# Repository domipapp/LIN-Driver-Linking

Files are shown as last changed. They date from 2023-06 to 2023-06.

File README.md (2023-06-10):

# LIN meghajtó illesztése STK3700 mikrokontrollerhez és visszapillantó tükör vezérlése számítógépről
A project az 5. féléves Témalaboratóium kurzus keretein belül valósult meg. A konzulensem Scherer Balázs volt.
A projekt során meg kellett tervezni egy nyákot olyan kapcsolással amely illeszthető STM3700 mikrokontrollerhez, számítőgéptől kapott LIN üzenetek
megfelelő feszültségszintre konvertálását el tudja végezni és képes elegendő áramot szolgáltani a visszapillantó tükör vezérléséhez.
Az üzenetek dekódolását és a tükör irányítását a mikrokontroller végzi.

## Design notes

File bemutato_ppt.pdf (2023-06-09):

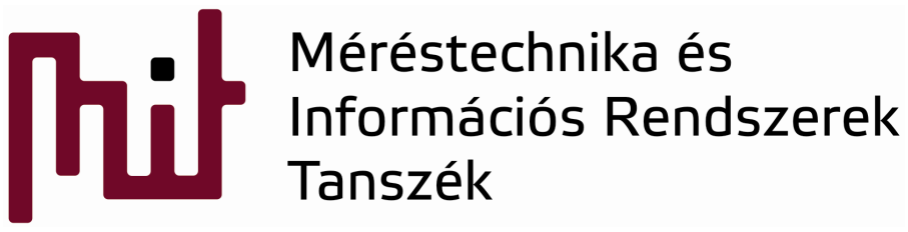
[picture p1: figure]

© BME-MIT 2022 Budapesti Műszaki és Gazdaságtudományi Egyetem Méréstechnika és Információs Rendszerek Tanszék

# BSc Témalaboratórium beszámoló

# Visszapillantó tükör vezérlése LIN hálózaton keresztül

# Papp Dominik Scherer Balázs

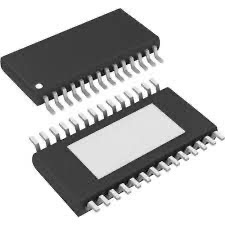
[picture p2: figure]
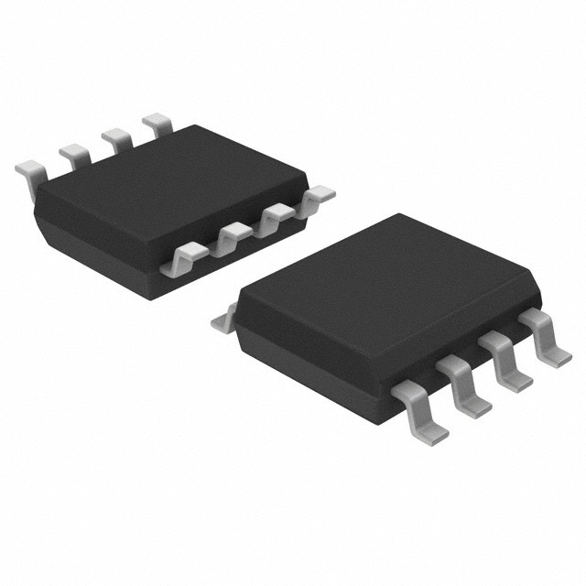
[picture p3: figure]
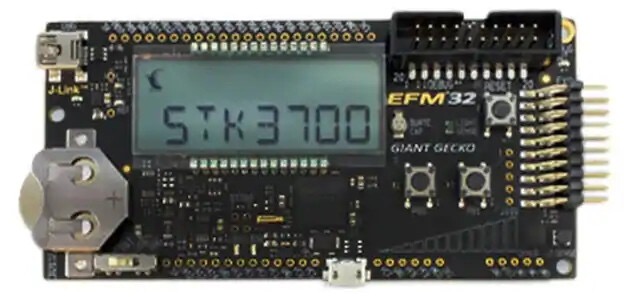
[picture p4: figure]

© BME-MIT 2022 | 2. fólia

# Feldatkírás

# - Motor vezérlés - LIN kommunikáció - Adatfeldolgozás mikrokontrollerrel

# - DRV8844PWPR - TJA1029T/20/1J - STK3700 fejlesztői kártya

# IC-k

# - LIN Adó-Vevő

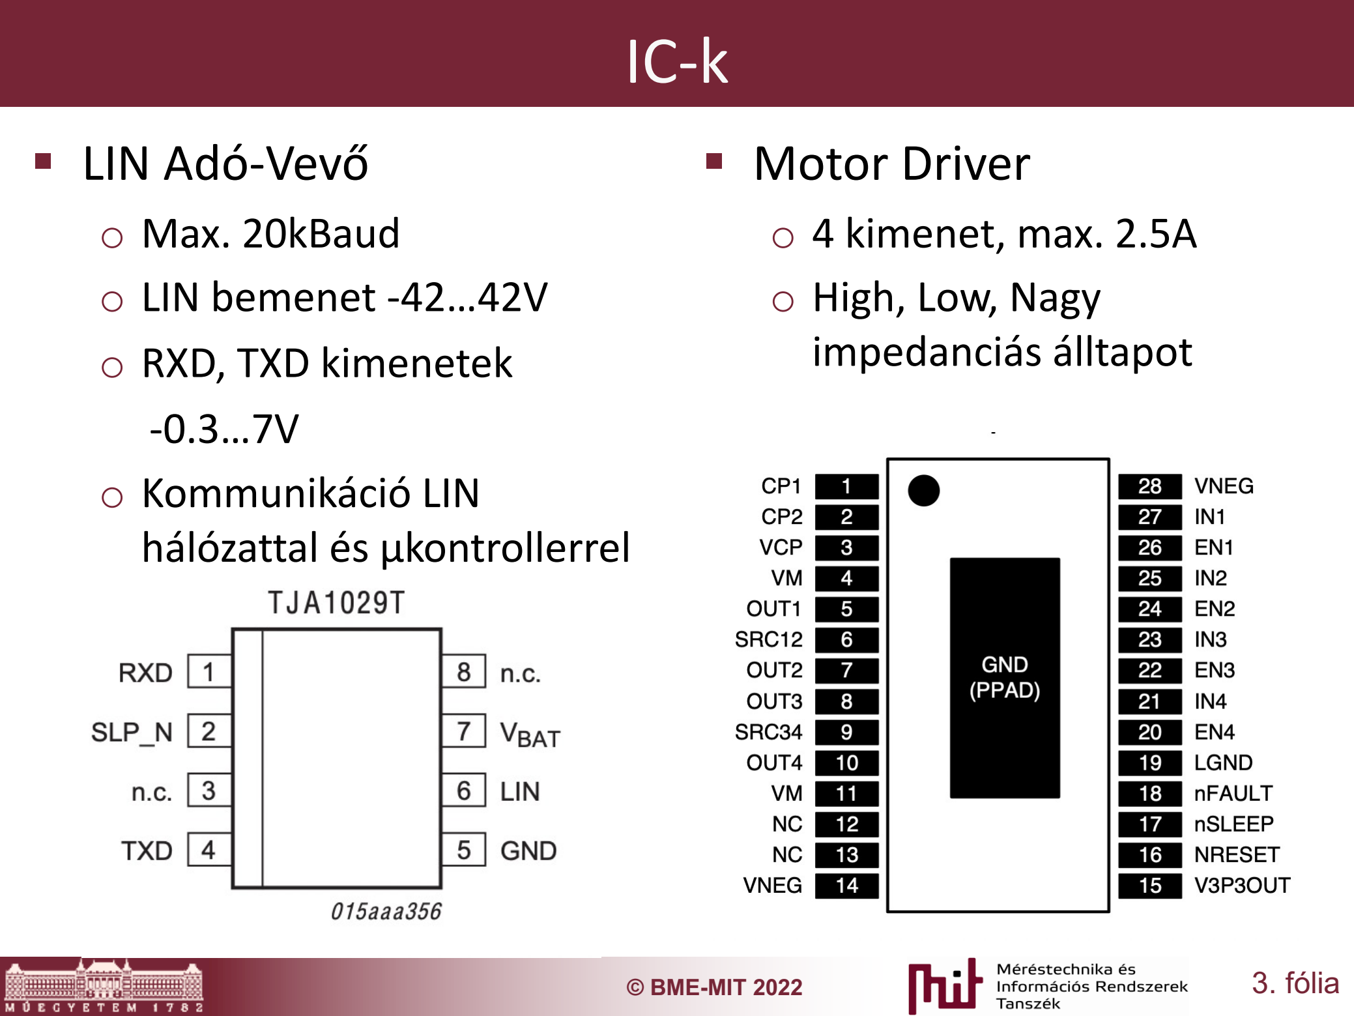
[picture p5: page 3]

© BME-MIT 2022 | 3. fólia

# - Max. 20kBaud - LIN bemenet -42…42V - RXD, TXD kimenetek

-0.3…7V

# - Kommunikáció LIN hálózattal és µkontrollerrel

# - Motor Driver

# - 4 kimenet, max. 2.5A - High, Low, Nagy impedanciás álltapot

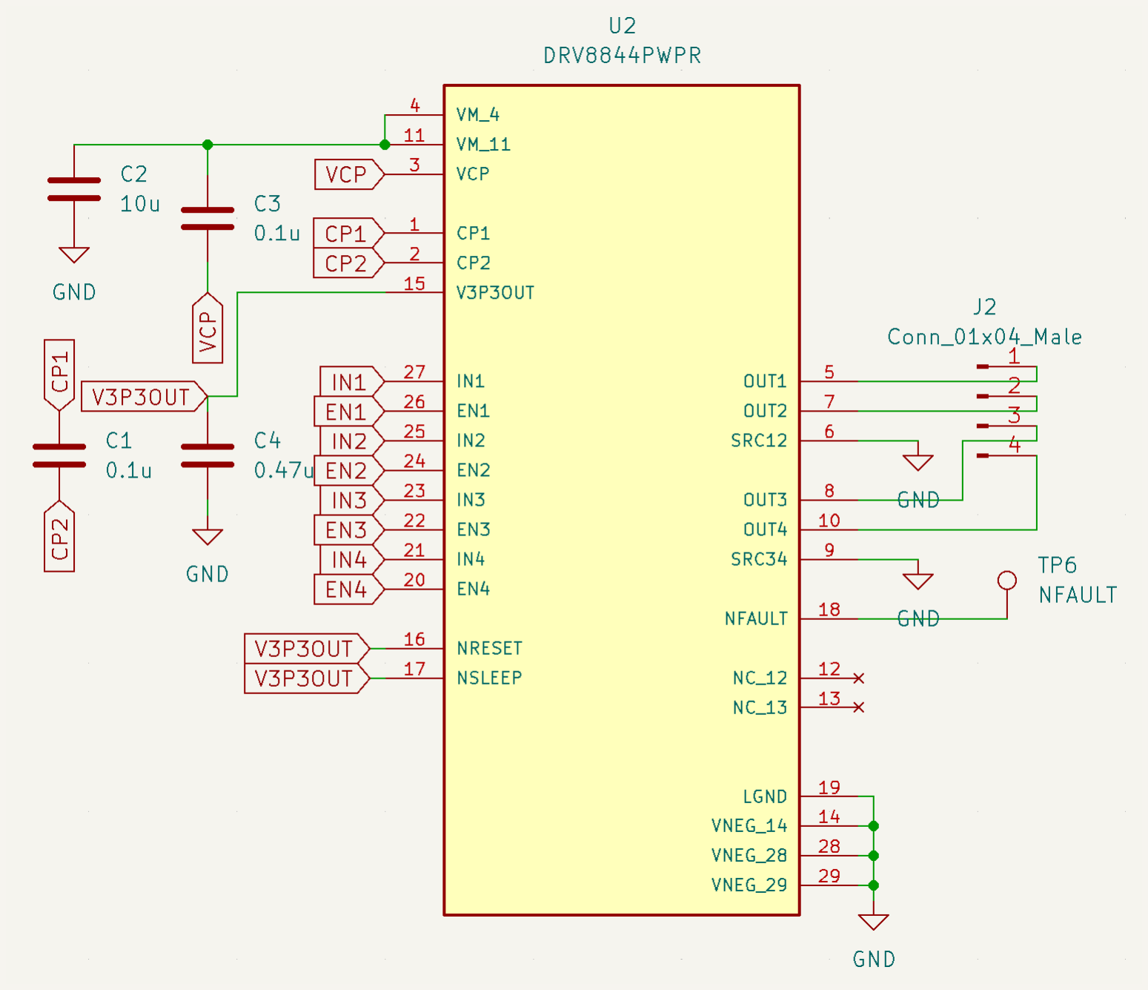
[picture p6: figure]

© BME-MIT 2022 | 4. fólia

# Kapcsolási rajz

# Kapcsolási rajz

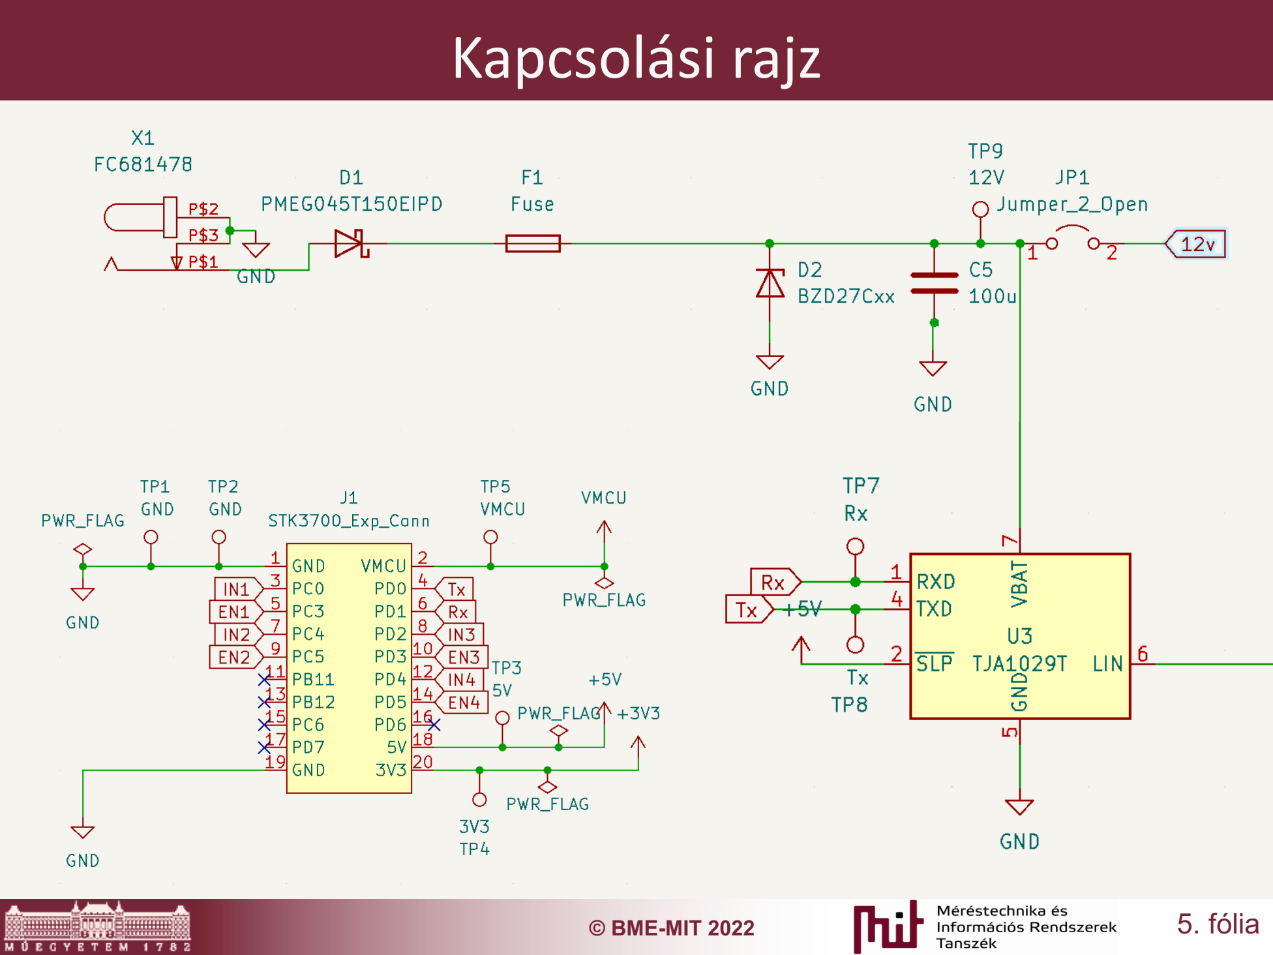
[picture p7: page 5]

© BME-MIT 2022 | 5. fólia

# NYÁK terv

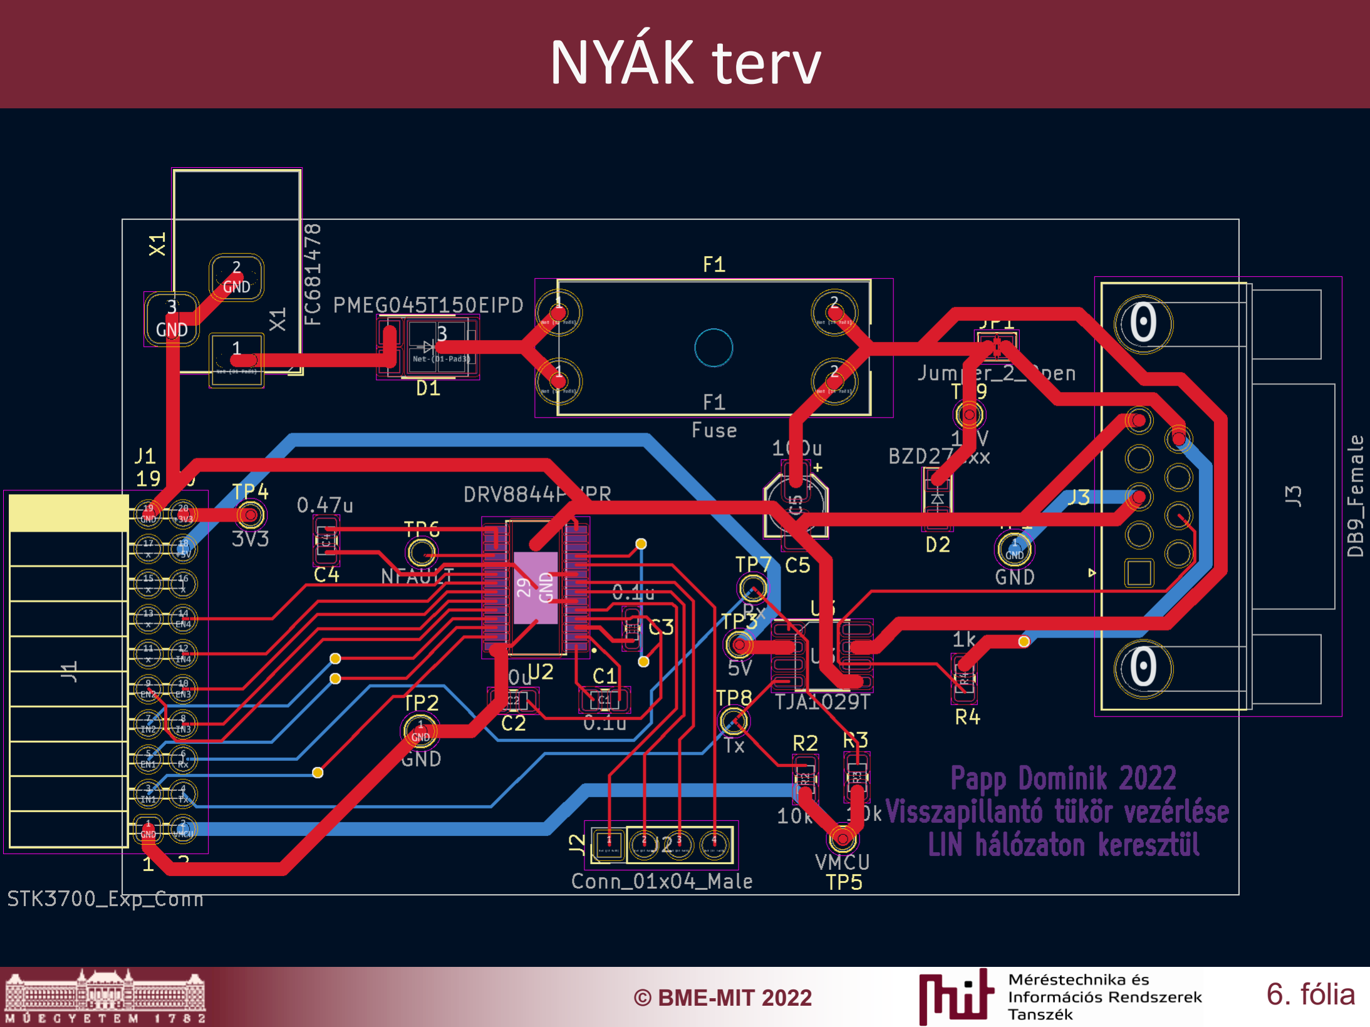
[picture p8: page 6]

© BME-MIT 2022 | 6. fólia

# LIN keret

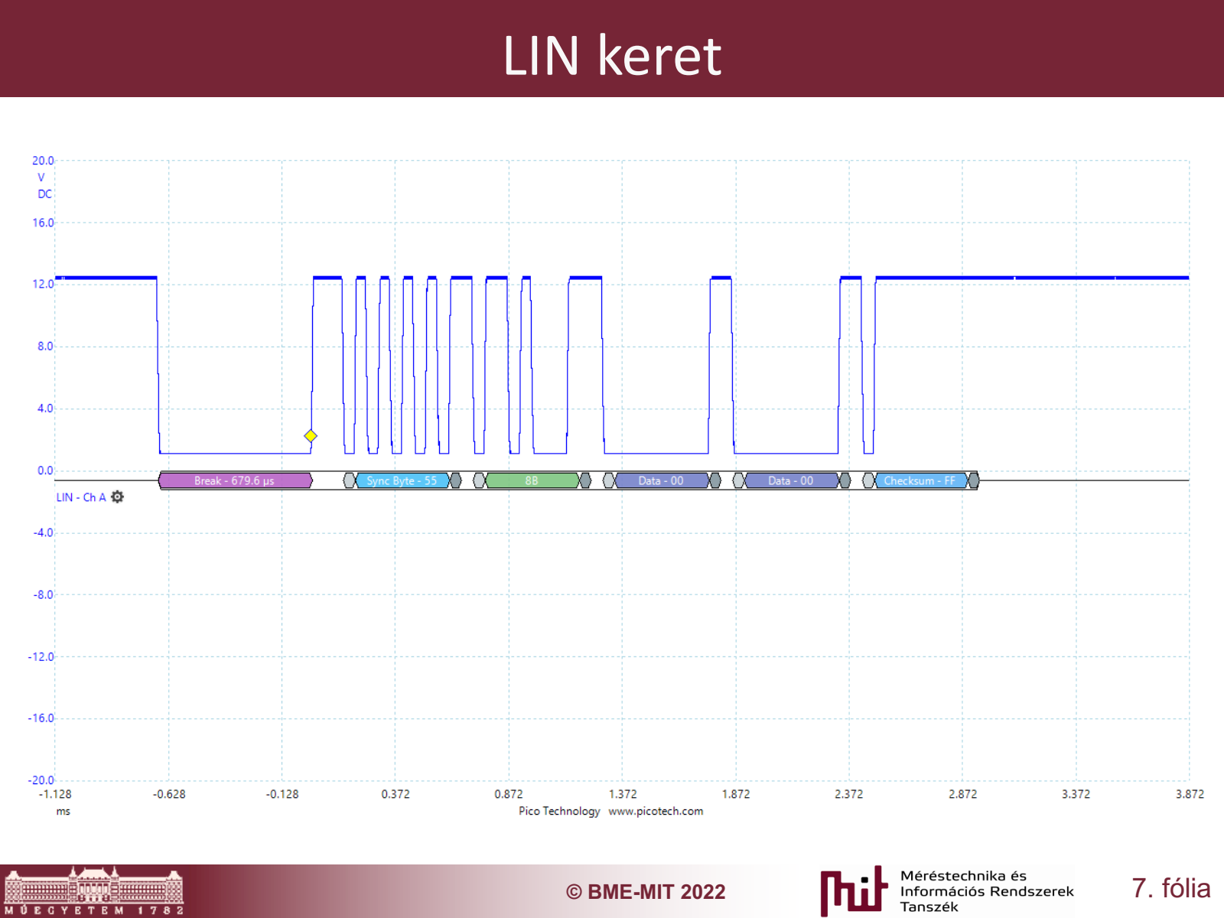
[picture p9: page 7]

© BME-MIT 2022 | 7. fólia

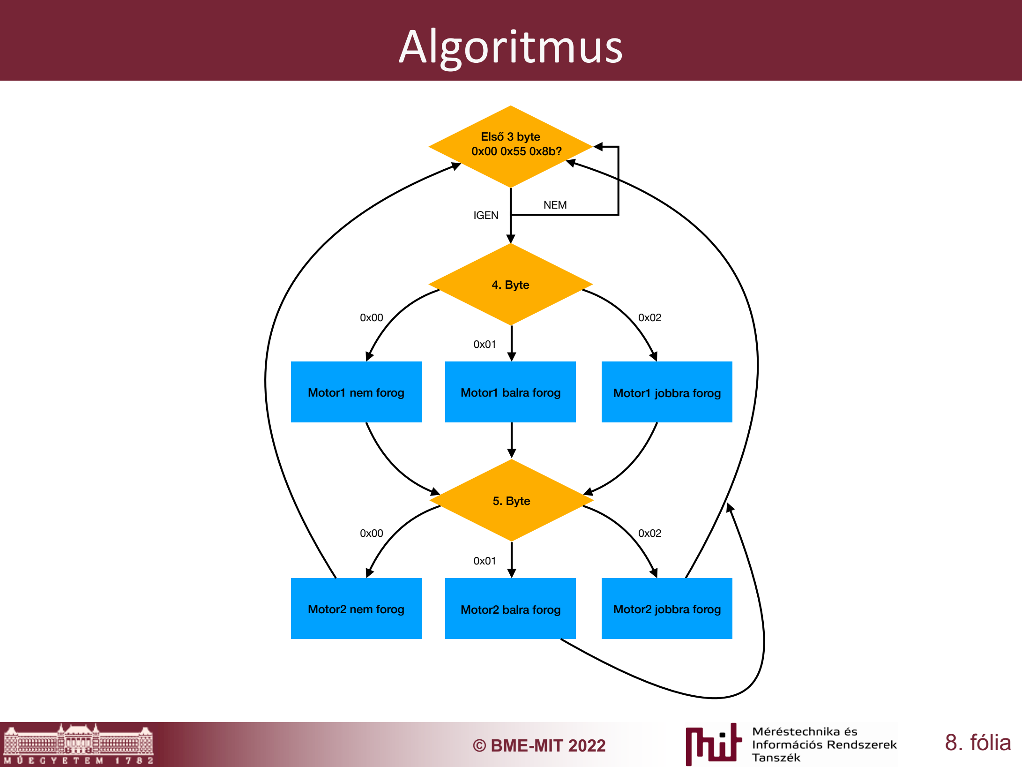
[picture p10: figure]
© BME-MIT 2022; 8. fólia; Algoritmus; Első 3 byte 0x00 0x55 0x8b?; 4. Byte; IGEN; NEM; Motor1 jobbra forog; 5. Byte; Motor2 nem forog; Motor2 balra forog; Motor1 nem forog; Motor1 balra forog; Motor2 jobbra forog

# Tapasztalatok

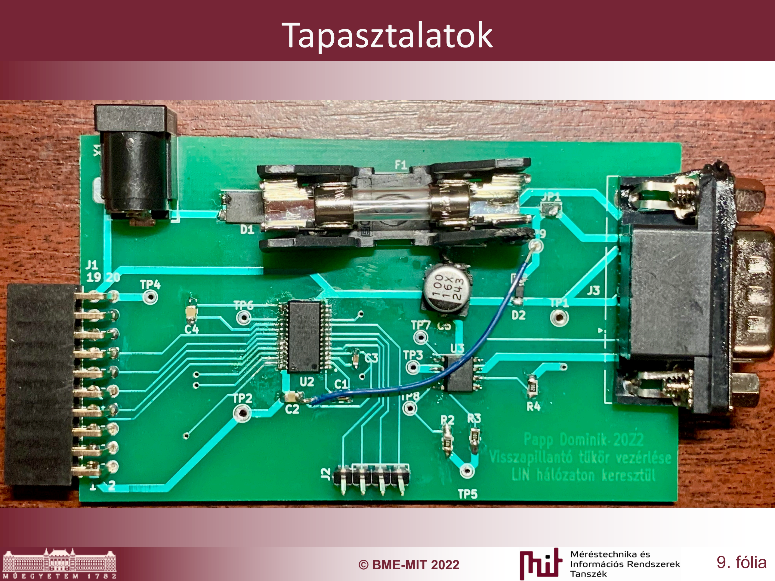
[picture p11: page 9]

© BME-MIT 2022 | 9. fólia

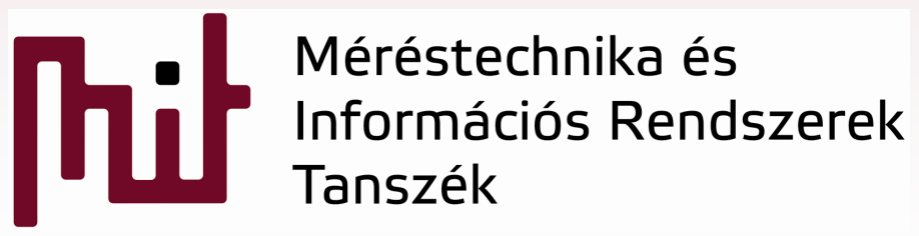
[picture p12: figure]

© BME-MIT 2022 Budapesti Műszaki és Gazdaságtudományi Egyetem Méréstechnika és Információs Rendszerek Tanszék

# BSc Témalaboratórium beszámoló

# Köszönöm a figyelmet!

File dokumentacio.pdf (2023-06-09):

- 1 -

# Visszapillantó tükör vezérlése LIN hálózaton keresztül

## Témalaboratórium dokumentáció

## 2022/23 I. Félév

# Papp Dominik Edvárd

## Konzulens: Scherer Balázs

- 2 -

## Tartalomjegyzék

Bevezetés | - 3 -
Feladat specifikáció | - 3 -
LIN meghajtó | - 3 -
Driver IC | - 3 -
Kapcsolási rajz | - 3 -
Táp kapcsolási rajza | - 3 -
STK3700 connector kapcsolási rajza | - 4 -
Driver IC kapcsolási rajza | - 4 -
LIN meghajtó kapcsolási rajza | - 5 -
NYÁK | - 5 -
NYÁK terv | - 5 -
Elkészült NYÁK és bemérés | - 5 -
LIN keret | - 6 -
Algoritmus | - 7 -
Irodalomjegyzék | - 8 -

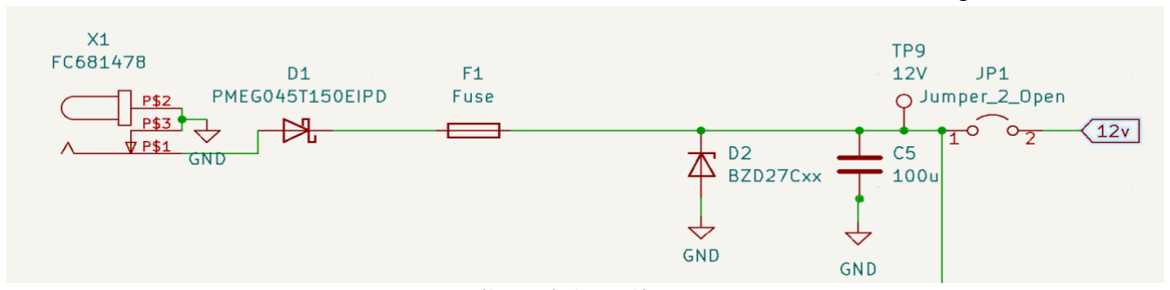
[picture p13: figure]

- 3 -

## Bevezetés

## Feladat specifikáció

A feladat egy olyan hálózat, kapcsolás megvalósítása volt, amely LIN protokoll és mikrokontroller használatával képes egy visszapillantó tükröt xy irányban vezérelni.
A motort vezérlő áramot ás feszültséget egy DRV8844-es IC-vel valósítottam meg. A LIN kommunikációt a számítógéppel és a mikrokontrollerrel egy TJA1029 IC végzi, a mikrokontroller pedig a BAMBI tárgyból kapott STK3700-as fejlesztői kártya.

## LIN meghajtó

A LIN meghajtó maximum 20 kBaudos sebességgel tud kommunikálni a számítógéppel is és a mikrokontrollerrel is. Az 1-es és 4-es (RXD, TXD) lábakon a mikrokontrollerrel kommunikál, a 6-os LIN lábon pedig a számítógéppel. Az IC a LIN lábon kapott -42...42 Voltos jelet -0.3...7 Voltos jellé tudja alakítani
és fordítva. Jelen kapcsolásban csak a

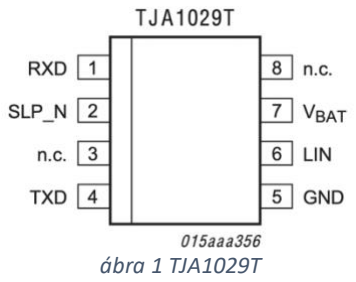
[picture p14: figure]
ábra 1 TJA1029T

feszültségkonverzió a feladata. Bővebb leírás megtalálható a
[3] irodalomban.

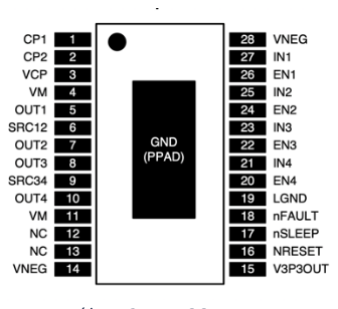
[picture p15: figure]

## Driver IC

A driver IC az IN1...4 és EN1...4 lábakkal vezérelhető. Az IN1 és EN1 az OUT1-et vezérlik és OUT2...4-re így tovább. EN bemenettel az állítható, hogy a kimenet nagyimpedanciás-e. EN 0 esetén nagyimpedanciás az OUT1. Az IN bemenettel pedig az állítható, hogy ha nem nagyimpedanciás a kimenet akkor Low vagy High értékű legyen az OUT kimenet. A kimenetek maximum 2.5A-t tudnak szolgáltatni. Bővebb leírás megtalálható a [2] irodalomban.

## Kapcsolási rajz

## Táp kapcsolási rajza

Alább látható a belső tápot előállító áramkör. X1 a külső tápbemenet, a D1 egy schottky dióda (polaritás elleni védelem), F1 egy olvadóbiztosíték (túláram elleni védelem), D2 egy zener dióda (túlfeszültség elleni védelem) és a C5 egy hidegítő elektrolit kondenzátor. A kondenzátor kimenete már használható belső táp ként.

ábra 2 DRV8844

ábra 3 Táp kapcsolási rajz

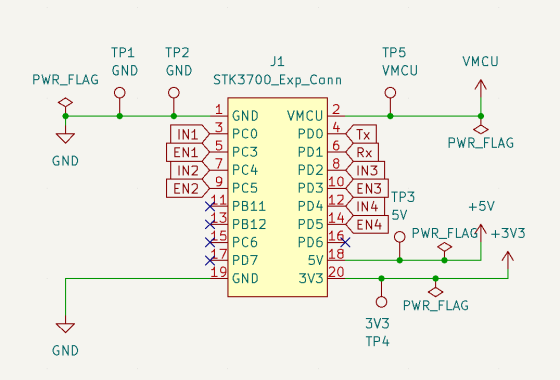
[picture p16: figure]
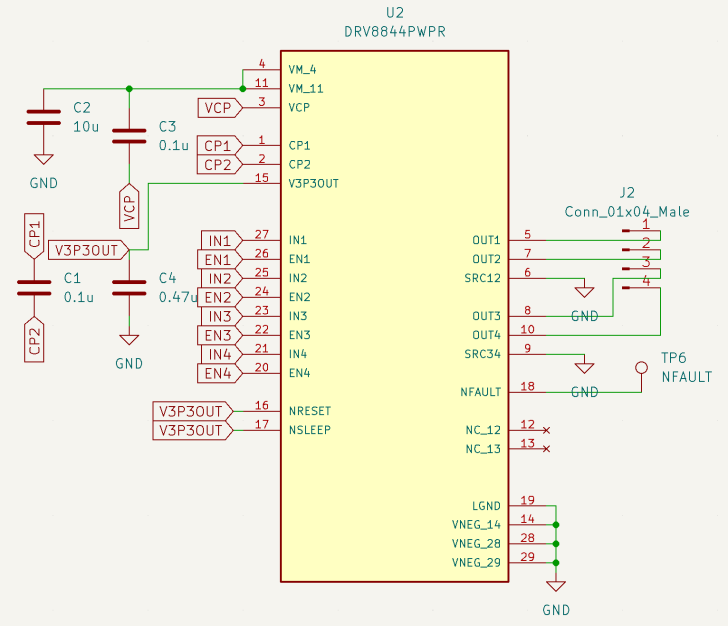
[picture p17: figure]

- 4 -

## STK3700 connector kapcsolási rajza

J1 az STK3700-as mikrokontroller kimeneti 20 pines tüskesorára csatlakozó connector. J1 a 3,5,7,9,8,10,12,14-es lábakon a Driver IC-re, a 4,6-os lábakon a LIN IC-re csatlakozik. Bővebb leírás a mikrokontroller kimeneti tüskesoráról megtalálható a [4] irodalomban.

## Driver IC kapcsolási rajza

Az ábra a driver IC kapcsolási rajza. Ahhoz, hogy működni tudjon, a
gyártó | által | előre | meghatározott
kapacitásokat kell kapcsolni bizonyos lábakra és bizonyos lábak közé. Az IC OUT1...4 kimenetei egy 4 pines tüskesorra csatlakoznak, a bemenetek pedig az STK3700 connectorra. A 4 pines tüskesoron fognak csatlakozni a visszapillantó tükör motorjai. Fontos megjegyezni, hogy a 4-es és 11-es lábakra rá kell kötni a tápot. Ez a kapcsolási rajzon nincs megtéve, ezt utólag korrigálni kellett. Részletesebb
leírás | a | kapcsolt | kondenzátorok
értékeiről | megtalálható | a | [2]
irodalomban.

ábra 4 STK3700 connector kapcsolási rajz

ábra 5 Driver IC kapcsolási rajz

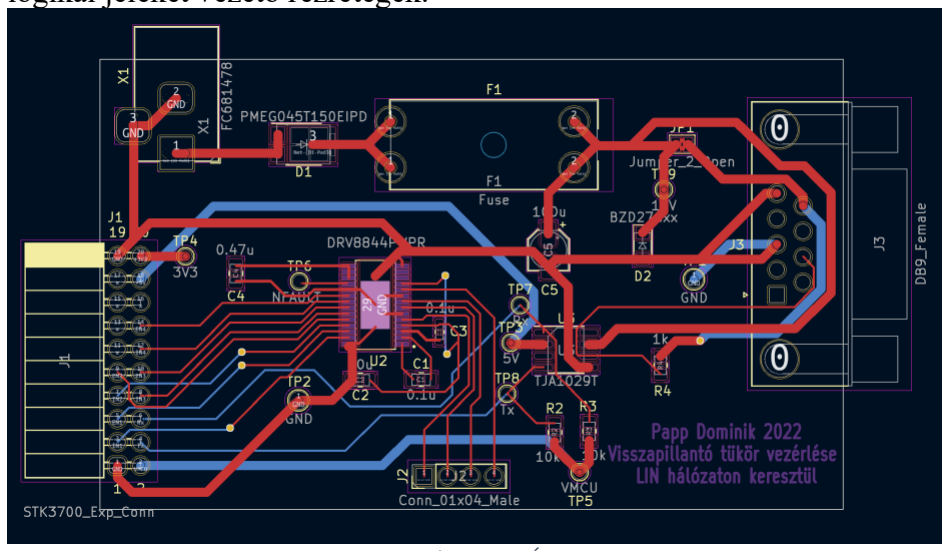
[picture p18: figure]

- 5 -

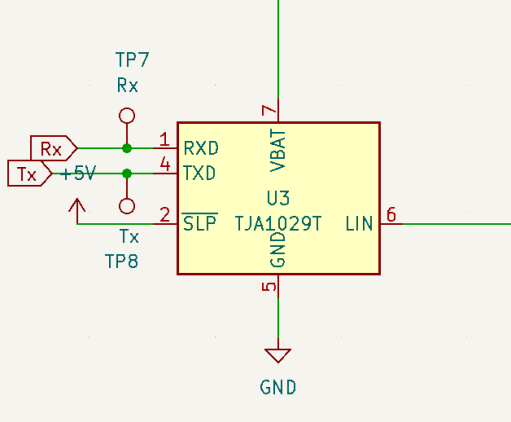
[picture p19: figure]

## LIN meghajtó kapcsolási rajza

A LIN úgy, mint a driver rá van kötve 10k-s felhúzó ellenállásokon keresztül az STK3700-as connectorra, így kommunikál a mikrokontrolleren lévő USART-tal. A LIN lába egy DB9-es csatlakozóra van rákötve, itt csatlakozik a számítógép az áramkörhöz.

## NYÁK

## NYÁK terv

Itt látható a fizikai megvalósítása a kapcsolási rajznak. Az látható, hogy a DB9-es az female és utólag kiderült, hogy az egyébként male. Emiatt kellett egy újraforrasztást végezni. Törekedtem a magas helykihasználásra. A táp látható, hogy nincs a C2 és C3 közös pontjára kötve. A táp és földvezetékek vastagabbak, mint a logikai jeleket vezető rézrétegek.

ábra 7 NYÁK terv

## Elkészült NYÁK és bemérés

A beméréshez szükséges:
1. Az elkészült NYÁK
2. Gecko kártya
3. Táp bemenet
4. LIN csatlakozó
5. Visszapillantó tükör vezetékei A LIN csatlakozó másik vége a számítógépre csatlakozik, innen küldjük a vezérlő jeleket. A visszapillantó tükörre az 5-ös megjelölésű vezetékekkel kapcsolódunk. A bemérés eredménye a 9-es ábrán látható. Egy olyan adatcsomagot sikerült lefotózni, amely a 0x00 0x00 hexa adatok miatt a tükör nem mozgatását kéri.

ábra 6 LIN meghajtó kapcsolási rajz

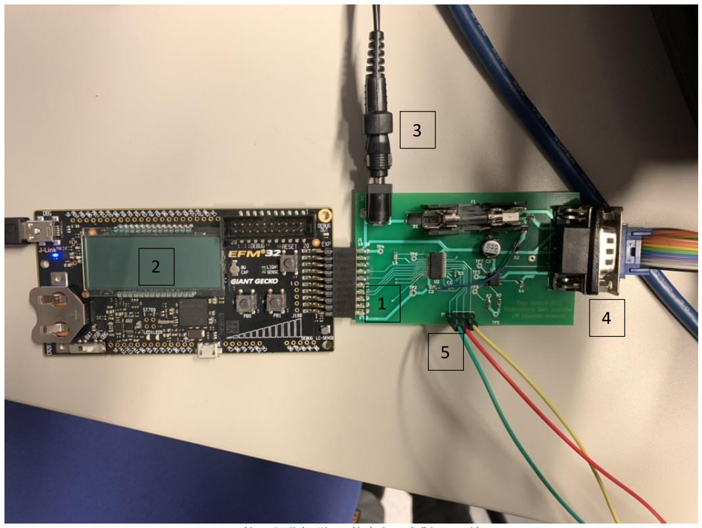
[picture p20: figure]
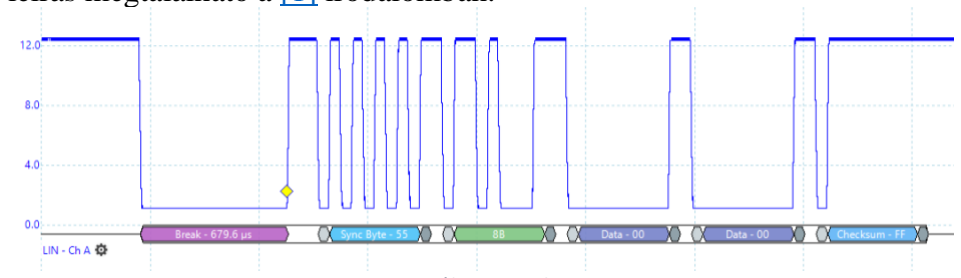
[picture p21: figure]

- 6 -

ábra 8 Elkészült nyák és bemérő kapcsolás

## LIN keret

A lin keret 6 byteból áll. Az első byte egy „break” jel, ez felébreszti a hálózatot. Hexában USART 8N1-es protokollal értelmezve ez 0x00.A második byte egy 0x55 szinkronizációs byte (01010101) majd még egy azonosító byte, ami az én esetemben 0x8b. A kötelező byteok után bármennyi byte jöhet, nekünk csak 2 fog, hogy a 2 motort melyik irányba kell forgatni. Az utolsó byte egy ellenőrző összeg, ezt figyelmen kívül hagyjuk. Az egyes byteokat USART 8N1-es protokoll szerint kell értelmezni! Ezért is használható a mikrokontrolleren az USART periféria. Bővebb leírás megtalálható a [1] irodalomban.

ábra 9 LIN keret

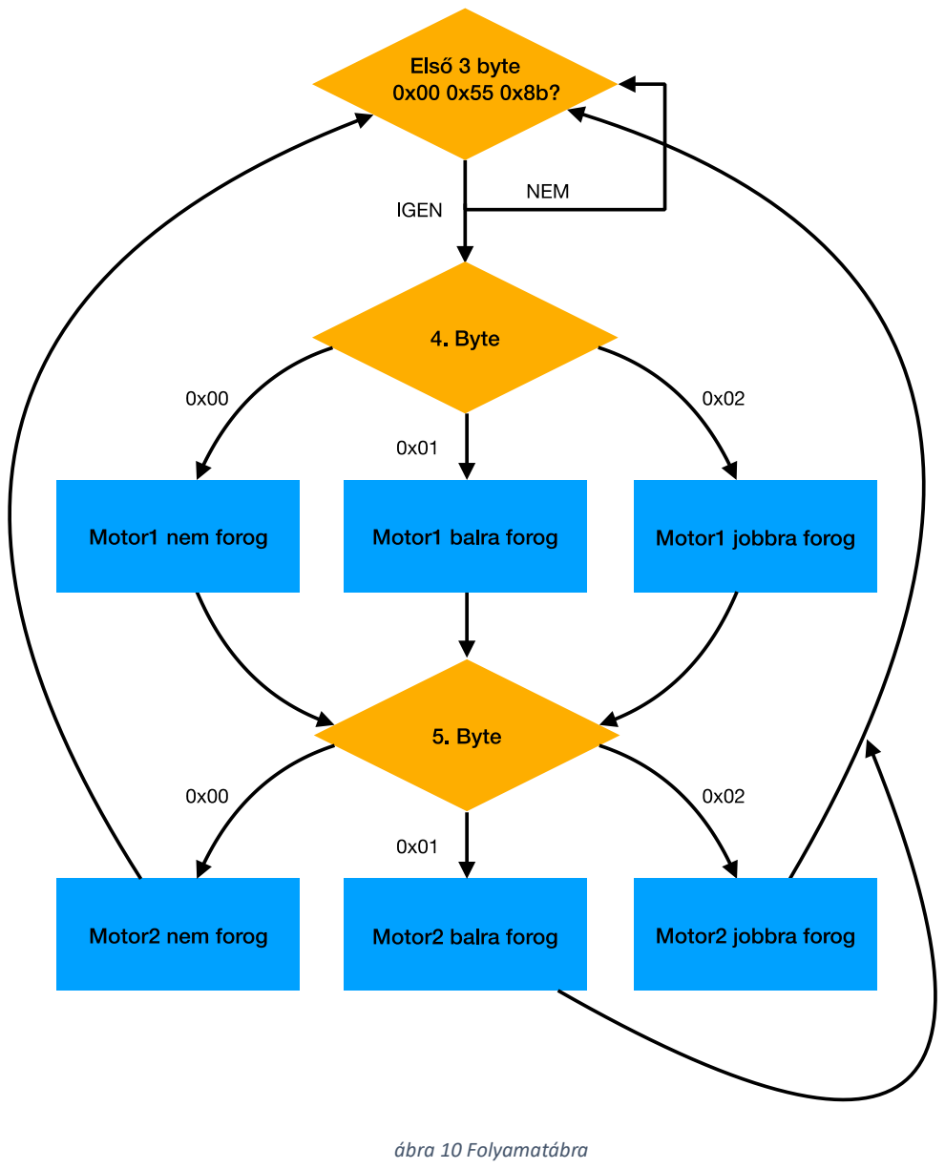
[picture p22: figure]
ábra 10 Folyamatábra

- 7 -

## Algoritmus

A mikrokontroller az alábbi algoritmust valósítja meg. Első körben mindent inicializál, 0-ba a lábakat és USART1-et használ a PD0 (Tx) és PD1 (Rx) lábakon. Ezek végrehajtása után végtelen ciklusban pörög.
Először megnézi, hogy 0x00 0x55 0x8b hexa értékek jöttek-e, ebben a sorrendben, majd igen esetén a következő 2 byte értéke szerint mozgatja a 4 pines tüskesoron csatlakozó motorokat. Az első byte a tüskesor 1-2 lábára kapcsolt motort, a második byte pedig a 2-3 lábakra kapcsolt motort vezérli.

- 8 -

## Irodalomjegyzék

[1] Scherer Balázs, dr. Tóth Csaba: "Autóipari kommunikációs hálózatok vizsgálata", Laboratóriumi mérések a Beágyazott és ambiens rendszerek laboratórium tárgyhoz BME MIT 2008-2014
[2] DRV8844 Driver IC adatlap: https://www.ti.com/lit/ds/symlink/drv8844.pdf?ts=1668644796480&ref_url=https%2 53A%252F%252Fwww.ti.com%252Fproduct%252FDRV8844%252Fpart-details%252FDRV8844PWPR (https://www.ti.com/lit/ds/symlink/drv8844.pdf?ts=1668644796480)
[3] TJA1029T LIN meghajtó IC adatlap: https://www.farnell.com/datasheets/2057133.pdf
[4] EFM32GG-STK3700 User Manual https://www.silabs.com/documents/public/user-guides/efm32gg-stk3700-ug.pdf

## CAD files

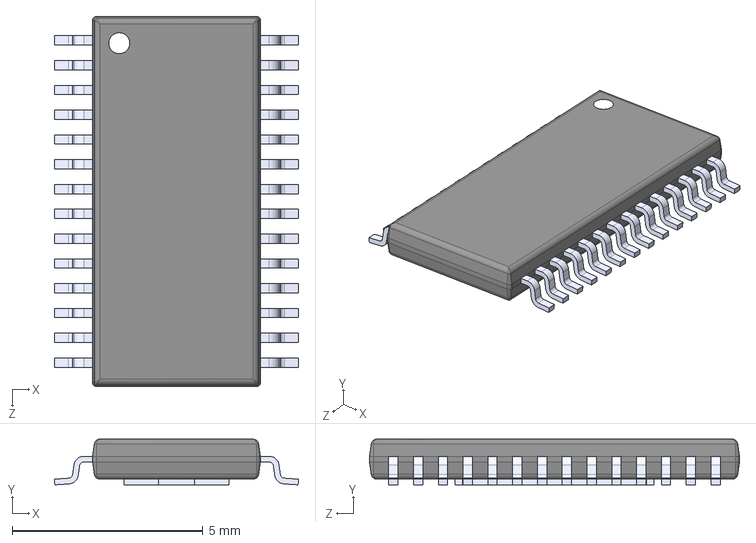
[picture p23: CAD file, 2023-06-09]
kicad/driver/DRV8844PWPR.step
6.40 x 1.20 x 9.70 mm

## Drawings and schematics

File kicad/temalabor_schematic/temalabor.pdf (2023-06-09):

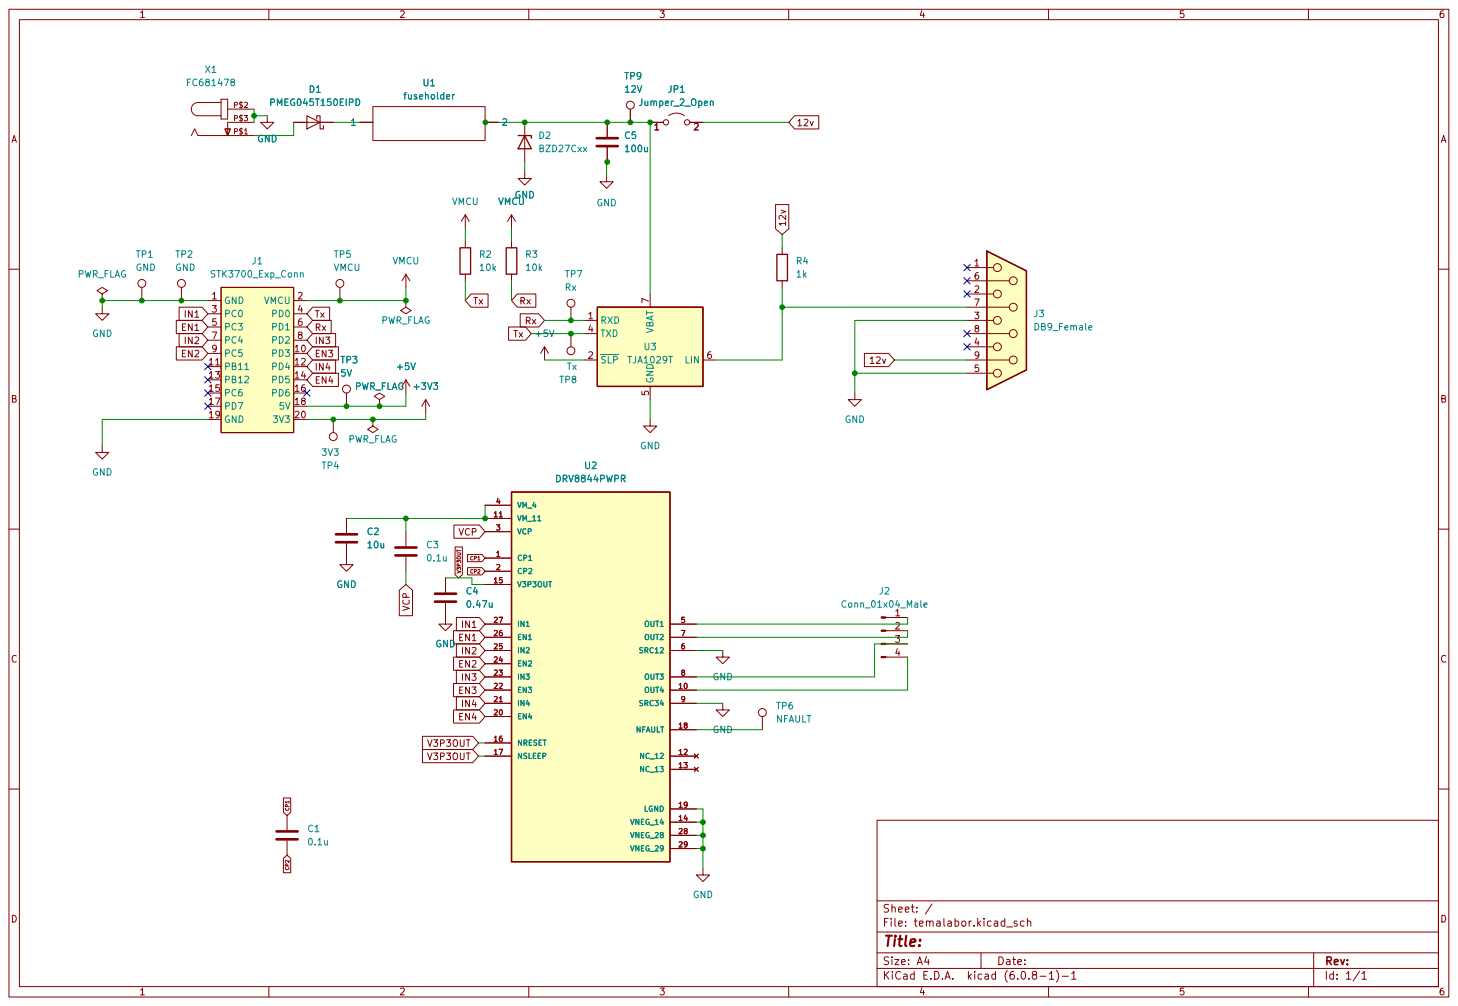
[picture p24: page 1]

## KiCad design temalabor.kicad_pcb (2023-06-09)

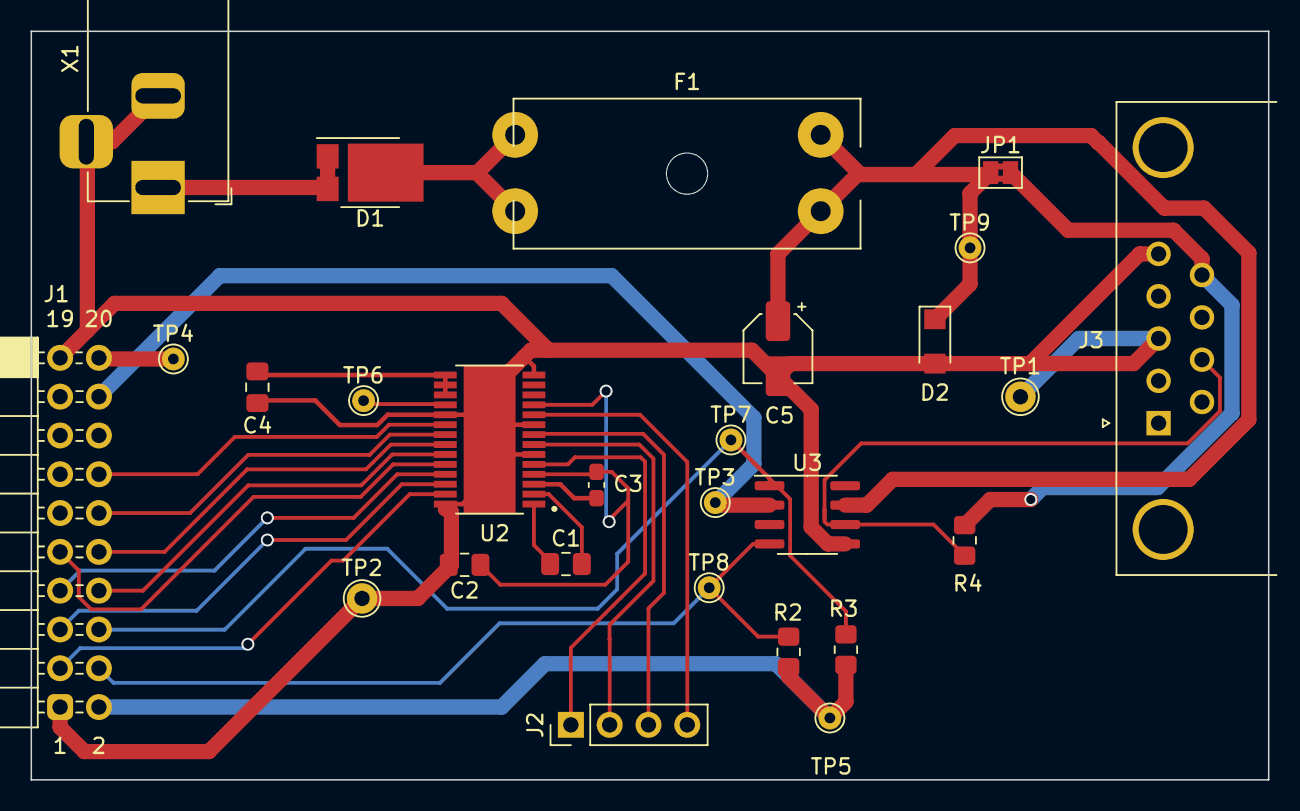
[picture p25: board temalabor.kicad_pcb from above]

Board: 2 copper layers, 81.0 x 49.0 mm, 27 parts (0 on the bottom side), 29 nets.

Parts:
C1: 0.1u; C_0805_2012Metric_Pad1.18x1.45mm_HandSolder
C2: 10u; C_0805_2012Metric_Pad1.18x1.45mm_HandSolder
C3: 0.1u; C_0603_1608Metric_Pad1.08x0.95mm_HandSolder
C4: 0.47u; C_0805_2012Metric_Pad1.18x1.45mm_HandSolder
C5: 100u; CP_Elec_4x3.9
D1: PMEG045T150EIPD; Nexperia_CFP15_SOT-1289
D2: BZD27Cxx; D_SMF
F1: Fuse; Fuseholder_Cylinder-5x20mm_Schurter_0031_8201_Horizontal_Op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
J1: STK3700_Exp_Conn; PinSocket_2x10_P2.54mm_Horizontal_Reversed
J2: Conn_01x04_Male; PinHeader_1x04_P2.54mm_Vertical
J3: DB9_Female; DSUB-9_Male_Horizontal_P2.77x2.84mm_EdgePinOffset4.94mm_Hou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
JP1: Jumper_2_Open; SolderJumper-2_P1.3mm_Bridged2Bar_Pad1.0x1.5mm
R2, R3: 10k; R_0805_2012Metric_Pad1.20x1.40mm_HandSolder
R4: 1k; R_0805_2012Metric_Pad1.20x1.40mm_HandSolder
TP1, TP2: GND; TestPoint_THTPad_D2.0mm_Drill1.0mm
TP3: 5V; TestPoint_THTPad_D1.5mm_Drill0.7mm
TP4: 3V3; TestPoint_THTPad_D1.5mm_Drill0.7mm
TP5: VMCU; TestPoint_THTPad_D1.5mm_Drill0.7mm
TP6: NFAULT; TestPoint_THTPad_D1.5mm_Drill0.7mm
TP7: Rx; TestPoint_THTPad_D1.5mm_Drill0.7mm
TP8: Tx; TestPoint_THTPad_D1.5mm_Drill0.7mm
TP9: 12V; TestPoint_THTPad_D1.5mm_Drill0.7mm
U2: DRV8844PWPR; IC_DRV8844PWPR
U3: TJA1029T; SOIC-8_3.9x4.9mm_P1.27mm
X1: FC681478; BarrelJack_Horizontal

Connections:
12v: J3.9, JP1.2 (B), R4.1
+3V3: J1.20 (3V3), TP4.1
+5V: J1.18 (5V), TP3.1, U3.2 (~SLP)
CP1: C1.1, U2.1 (CP1)
CP2: C1.2, U2.2 (CP2)
EN1: J1.5 (PC3), U2.26 (EN1)
EN2: J1.9 (PC5), U2.24 (EN2)
EN3: J1.10 (PD3), U2.22 (EN3)
EN4: J1.14 (PD5), U2.20 (EN4)
GND: C2.2, C4.2, C5.2, D2.2 (A), J1.1 (GND), J1.19 (GND), J3.3, J3.5, TP1.1, TP2.1, U2.6 (SRC12), U2.9 (SRC34), U2.14 (VNEG_14), U2.19 (LGND), U2.28 (VNEG_28), U2.29 (VNEG_29), U3.5 (GND), X1.2, X1.3
IN1: J1.3 (PC0), U2.27 (IN1)
IN2: J1.7 (PC4), U2.25 (IN2)
IN3: J1.8 (PD2), U2.23 (IN3)
IN4: J1.12 (PD4), U2.21 (IN4)
unnamed: C2.1, C3.1, U2.4 (VM_4), U2.11 (VM_11)
unnamed: C5.1, D2.1 (K), F1.2, JP1.1 (A), TP9.1, U3.7 (VBAT)
unnamed: D1.1 (A), D1.2 (A), X1.1
unnamed: D1.3 (K), F1.1
unnamed: J2.1, U2.5 (OUT1)
unnamed: J2.2, U2.7 (OUT2)
unnamed: J2.3, U2.8 (OUT3)
unnamed: J2.4, U2.10 (OUT4)
unnamed: J3.7, R4.2, U3.6 (LIN)
unnamed: TP6.1, U2.18 (NFAULT)
Rx: J1.6 (PD1), R3.2, TP7.1, U3.1 (RXD)
Tx: J1.4 (PD0), R2.2, TP8.1, U3.4 (TXD)
V3P3OUT: C4.1, U2.15 (V3P3OUT), U2.16 (NRESET), U2.17 (NSLEEP)
VCP: C3.2, U2.3 (VCP)
VMCU: J1.2 (VMCU), R2.1, R3.1, TP5.1

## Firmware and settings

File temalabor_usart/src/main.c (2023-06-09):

#include "em_device.h"
#include "em_chip.h"
#include <stdio.h>
#include "em_usart.h"
#include "em_cmu.h"
#include "retargetserial.h"
#include "em_system.h"
#include "em_gpio.h"
#include "em_core.h"
#include "motor_vezerles.h"




int main(void)
{
	USART_InitAsync_TypeDef UART1_init = USART_INITASYNC_DEFAULT;
  /* Chip errata */
  CHIP_Init();

//  CMU ->HFPERCLKEN0 |= CMU_HFPERCLKEN0_GPIO;

  //orajel (ado-vevo, nem kommunikacio
  //  CMU_ClockEnable(CMU_Clock_TypeDef clock, bool enable);
    CMU_ClockEnable(cmuClock_GPIO, true);
    CMU_ClockEnable(cmuClock_USART1, true);

  //lab engedelezesek es minden 0-ba allitasa
    //USART_Tx
  GPIO_PinModeSet(gpioPortD, 0, gpioModePushPull,1);
  GPIO_PinOutClear(gpioPortD, 0);
    //USART_Rx
  GPIO_PinModeSet(gpioPortD, 1, gpioModeInput,1);
   GPIO_PinOutClear(gpioPortD, 1);
    //IN1
  GPIO_PinModeSet(gpioPortC, 0, gpioModePushPull,1);
  GPIO_PinOutClear(gpioPortC, 0);
    //EN1
  GPIO_PinModeSet(gpioPortC, 3, gpioModePushPull,1);
  GPIO_PinOutClear(gpioPortC, 3);
  	//IN2
  GPIO_PinModeSet(gpioPortC, 4, gpioModePushPull,1);
  GPIO_PinOutClear(gpioPortC, 4);
  	//EN2
  GPIO_PinModeSet(gpioPortC, 5, gpioModePushPull,1);
  GPIO_PinOutClear(gpioPortC, 5);
    //IN3
  GPIO_PinModeSet(gpioPortD, 2, gpioModePushPull,1);
  GPIO_PinOutClear(gpioPortD, 2);
    //EN3
  GPIO_PinModeSet(gpioPortD, 3, gpioModePushPull,1);
  GPIO_PinOutClear(gpioPortD, 3);
    //IN4
  GPIO_PinModeSet(gpioPortD, 4, gpioModePushPull,1);
  GPIO_PinOutClear(gpioPortD, 4);
    //EN4
  GPIO_PinModeSet(gpioPortD, 5, gpioModePushPull,1);
  GPIO_PinOutClear(gpioPortD, 5);


  //UART felkonfiguralasa
	UART1_init.baudrate = 19200;
	UART1_init.databits = usartDatabits8;
	UART1_init.parity = usartNoParity;
	UART1_init.stopbits = usartStopbits1;

  //USART konfiguralasa
  //USART_InitAsync(USART_TypeDef *usart, const USART_InitAsync_TypeDef *init)
	USART_InitAsync(USART1, &UART1_init);

  USART1 -> ROUTE |= USART_ROUTE_LOCATION_LOC1;
  USART1 -> ROUTE |= USART_ROUTE_RXPEN;
  USART1 -> ROUTE |= USART_ROUTE_TXPEN;
  USART_Enable(USART1,usartEnable);

  /* Infinite loop */
  uint8_t	pre = 0;
  uint8_t	m1 = 0;
  uint8_t	m2 = 0;


  while (1) {
	  pre = USART_Rx(USART1);//ezzel ellenorizzuk, hogy mik jottek
	  if(pre == 0x00){
		  pre = USART_Rx(USART1);
		  if(pre == 0x55){
			  pre = USART_Rx(USART1);
			  if(pre == 0x8b){
				  m1 = USART_Rx(USART1);
				  	  if(m1 == 0x02){//M1 motor jobbra forog
				  		  setOut1();
				  		  clearOut2();
				  		  disableOut3();
				  	  }
				  	  if(m1 == 0x01){//M1 motor balra forog
				  		  clearOut1();
				  		  setOut2();
				  		  disableOut3();
				  	  }
				  	  if(m1 == 0x00){//M1 motor nem forog
				  		disableOut1();
				  	  }
				  m2 = USART_Rx(USART1);
					  if(m2 == 0x01){//M2 motor jobbra forog
						  setOut2();
						  clearOut3();
						  disableOut1();
					  }
					  if(m2 == 0x02){//M2 motor balra forog
						  clearOut2();
						  setOut3();
						  disableOut1();
					  }
					  if(m2 == 0x00){//M2 motor nem forog
						  disableOut3();
					  }
			  	  }
		  	  }
	  }
  }
}

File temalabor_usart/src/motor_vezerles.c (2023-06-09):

#include "em_device.h"
#include "em_chip.h"
#include "em_gpio.h"
#include "em_usart.h"
#include "em_cmu.h"
void setOut1(void){
	  GPIO_PinOutSet(gpioPortC, 0);//IN1
	  GPIO_PinOutSet(gpioPortC, 3);//EN1
}
void clearOut1(void){
	  GPIO_PinOutClear(gpioPortC, 0);//IN1
	  GPIO_PinOutSet(gpioPortC, 3);//EN1
}
void disableOut1(void){
	  GPIO_PinOutClear(gpioPortC, 0);//IN1
	  GPIO_PinOutClear(gpioPortC, 3);//EN1
}



void setOut2(void){
	  GPIO_PinOutSet(gpioPortC, 4);//IN2
	  GPIO_PinOutSet(gpioPortC, 5);//EN2
}
void clearOut2(void){
	  GPIO_PinOutClear(gpioPortC, 4);//IN2
	  GPIO_PinOutSet(gpioPortC, 5);//EN2
}
void disableOut2(void){
	  GPIO_PinOutClear(gpioPortC, 4);//IN2
	  GPIO_PinOutClear(gpioPortC, 5);//EN2
}



void setOut3(void){
	  GPIO_PinOutSet(gpioPortD, 2);//IN3
	  GPIO_PinOutSet(gpioPortD, 3);//EN3
}
void clearOut3(void){
	  GPIO_PinOutClear(gpioPortD, 2);//IN3
	  GPIO_PinOutSet(gpioPortD, 3);//EN3
}
void disableOut3(void){
	  GPIO_PinOutClear(gpioPortD, 2);//IN3
	  GPIO_PinOutClear(gpioPortD, 3);//EN3
}
